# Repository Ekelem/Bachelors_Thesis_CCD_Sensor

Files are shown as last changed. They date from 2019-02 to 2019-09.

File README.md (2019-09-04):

# Bakalárska práca
Bakalárska práca VUT FIT, ROZŠIŘUJÍCÍ MODUL S CCD SENZOREM PRO VÝUKOVÝ KIT MINERVA

# Schémy

[Main](https://github.com/Ekelem/Bachelors_Thesis/blob/master/docs/ccdmodule.pdf)

[Image Sensor](https://github.com/Ekelem/Bachelors_Thesis/blob/master/docs/ImageSensor-Sheet5C7E7D75.pdf)

[Power Supply](https://github.com/Ekelem/Bachelors_Thesis/blob/master/docs/PowerSupply-Sheet5C7CB2BF.pdf)

# Preview

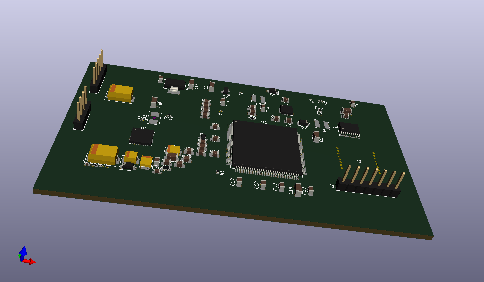
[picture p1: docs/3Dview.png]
alt Preview Preview


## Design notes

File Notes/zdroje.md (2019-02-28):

# Schémy
## Cam84 project
http://astroccd.org/wp-content/uploads/2015/05/CCD_Cam84_v41_sch.png
http://astroccd.org/2015/04/cam84/
https://stargazerslounge.com/topic/268504-a-diy-ccd-camera/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

## openmv boards (po digitalizácií môže byť použitý rovnaký image processing ako u CMOS kamier)
https://github.com/openmv/openmv-boards

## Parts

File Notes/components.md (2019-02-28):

#Súčiastky

## MCU
https://www.digikey.cz/product-detail/en/stmicroelectronics/STM32F765VGT6/497-16630-ND/6137841

## MPZ1608S181ATAH0
https://www.digikey.cz/product-detail/en/tdk-corporation/MPZ1608S181ATAH0/445-5220-1-ND/2117954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

## TPS65130 step up from 5 to 15 V and -8 V
https://www.mouser.sk/ProductDetail/Texas-Instruments/TPS65130RGER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

## Servo motor
https://www.gme.cz/servomotor-9g

## ICX098BQ
http://pdf1.alldatasheet.com/datasheet-pdf/view/88220/SONY/ICX098BQ.html
https://www.ebay.com/itm/1-x-ICXO98-ICX098-ICX098BQ-A-Progressive-Scan-CCD-Image-Sensor/183661486819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

119 Kč

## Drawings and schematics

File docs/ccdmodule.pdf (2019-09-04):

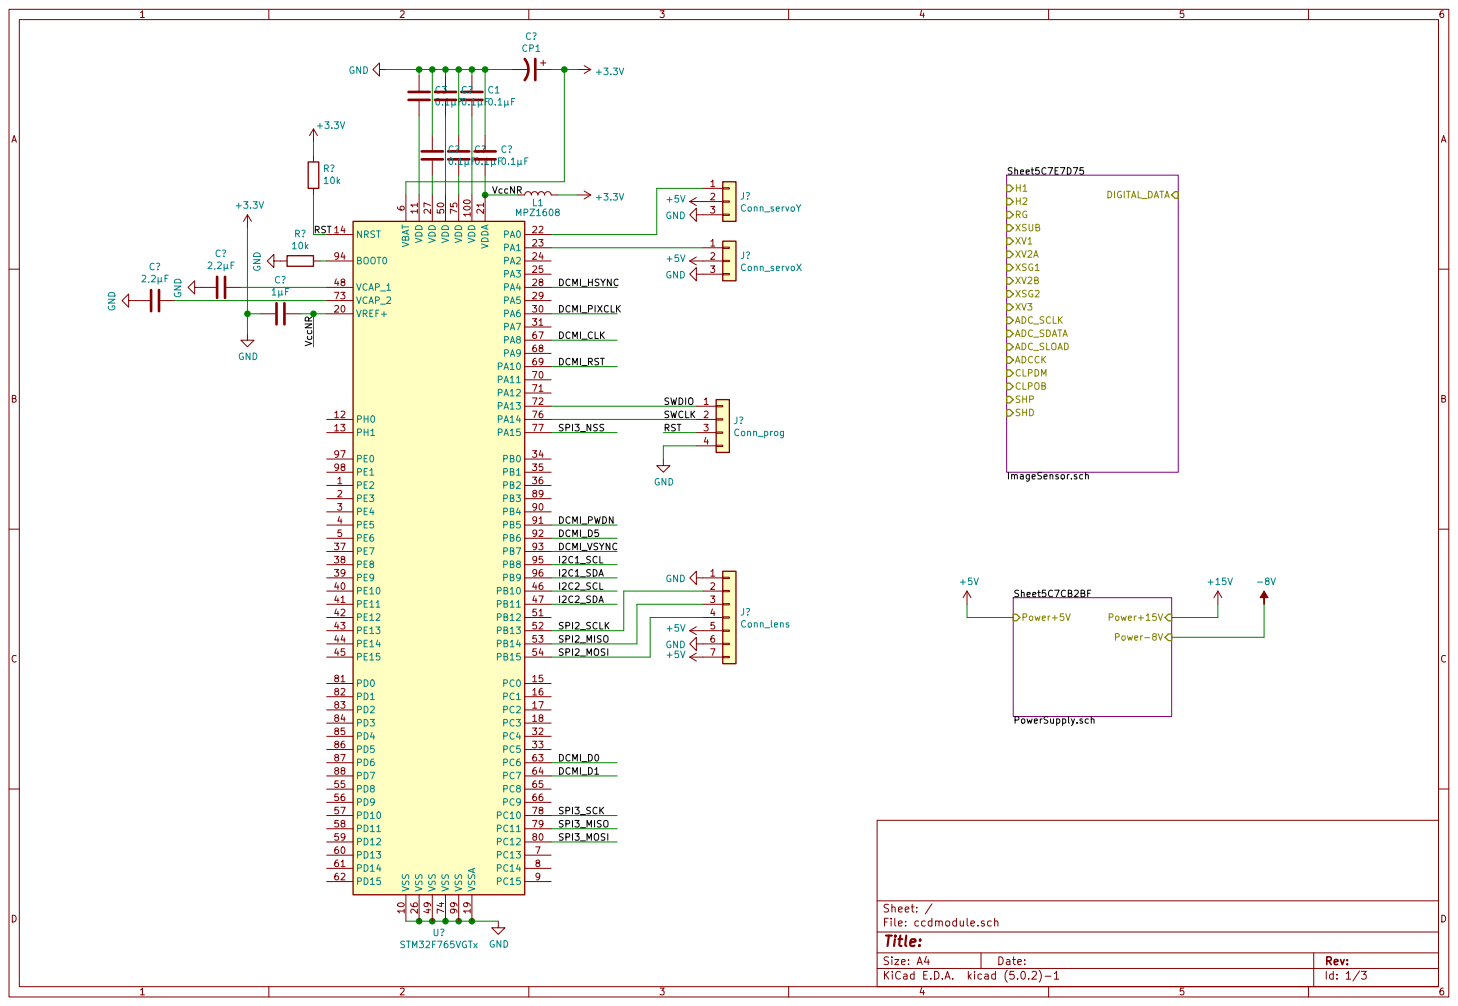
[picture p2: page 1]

Id: 1/3 Title: File: ccdmodule.sch Sheet: /

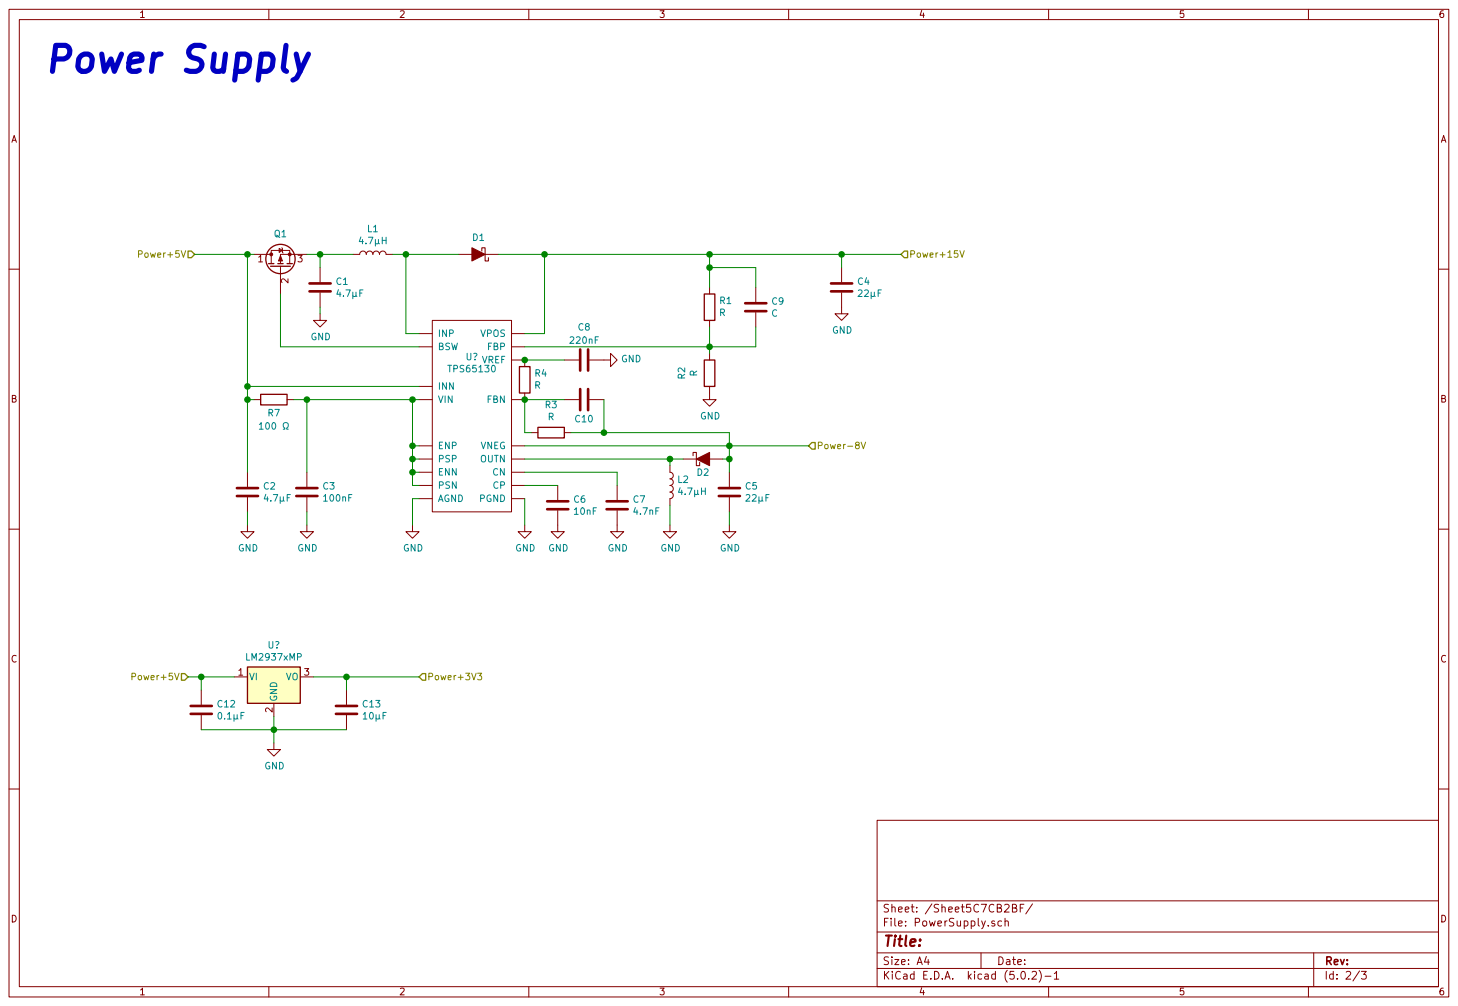
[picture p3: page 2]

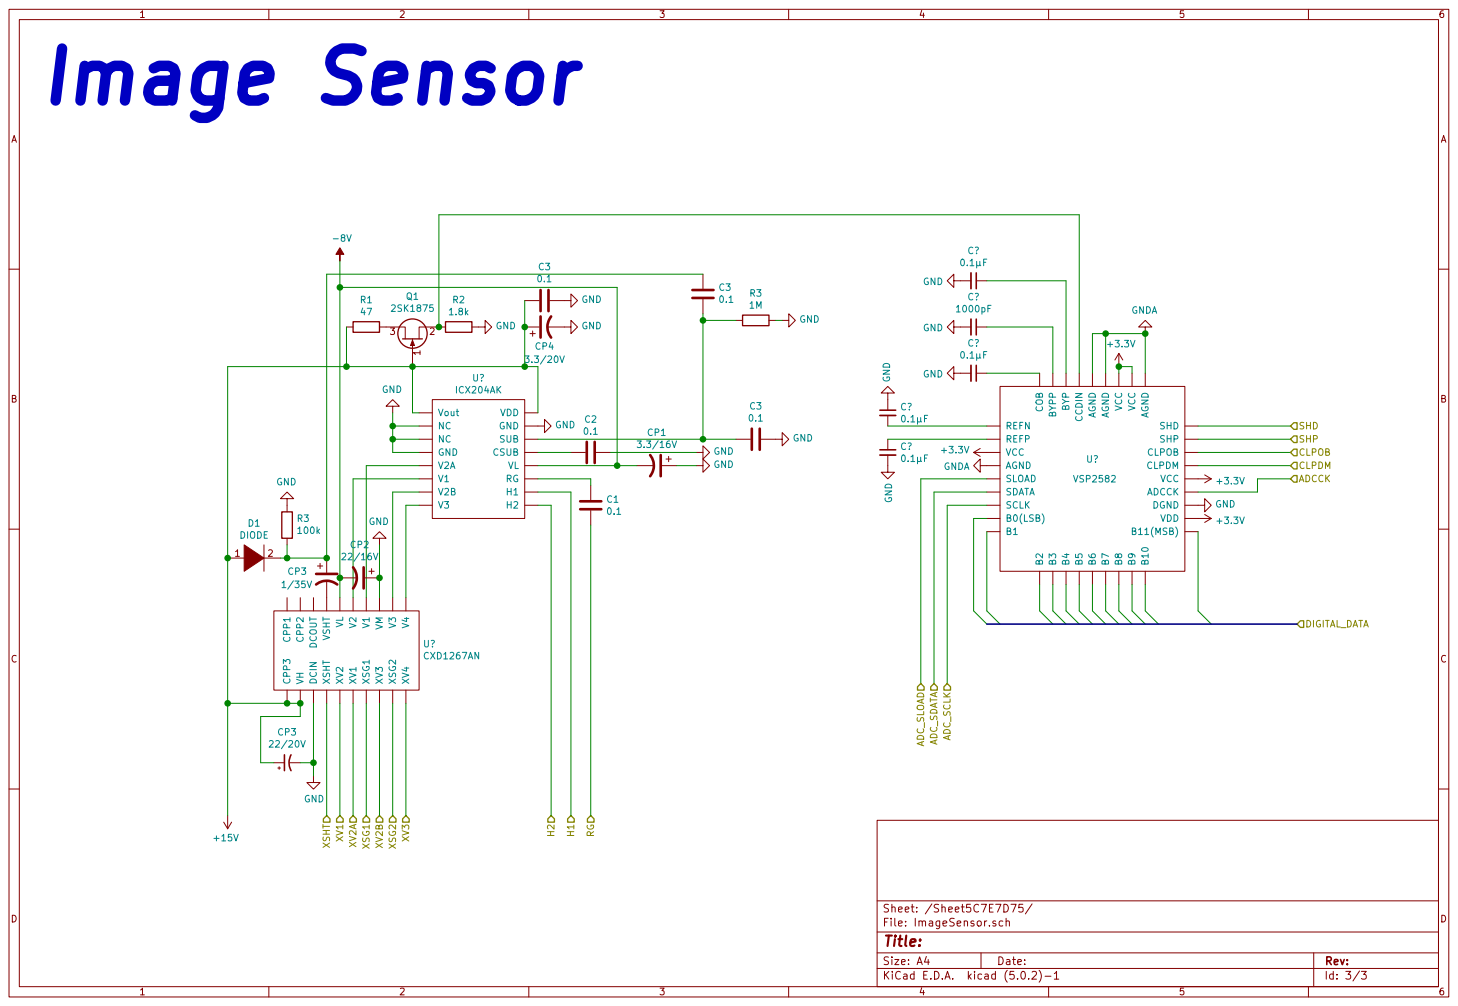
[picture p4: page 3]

File: ImageSensor.sch Sheet: /Sheet5C7E7D75/ Image Sensor

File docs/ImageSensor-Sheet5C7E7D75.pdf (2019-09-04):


File: ImageSensor.sch Sheet: /Sheet5C7E7D75/ Image Sensor


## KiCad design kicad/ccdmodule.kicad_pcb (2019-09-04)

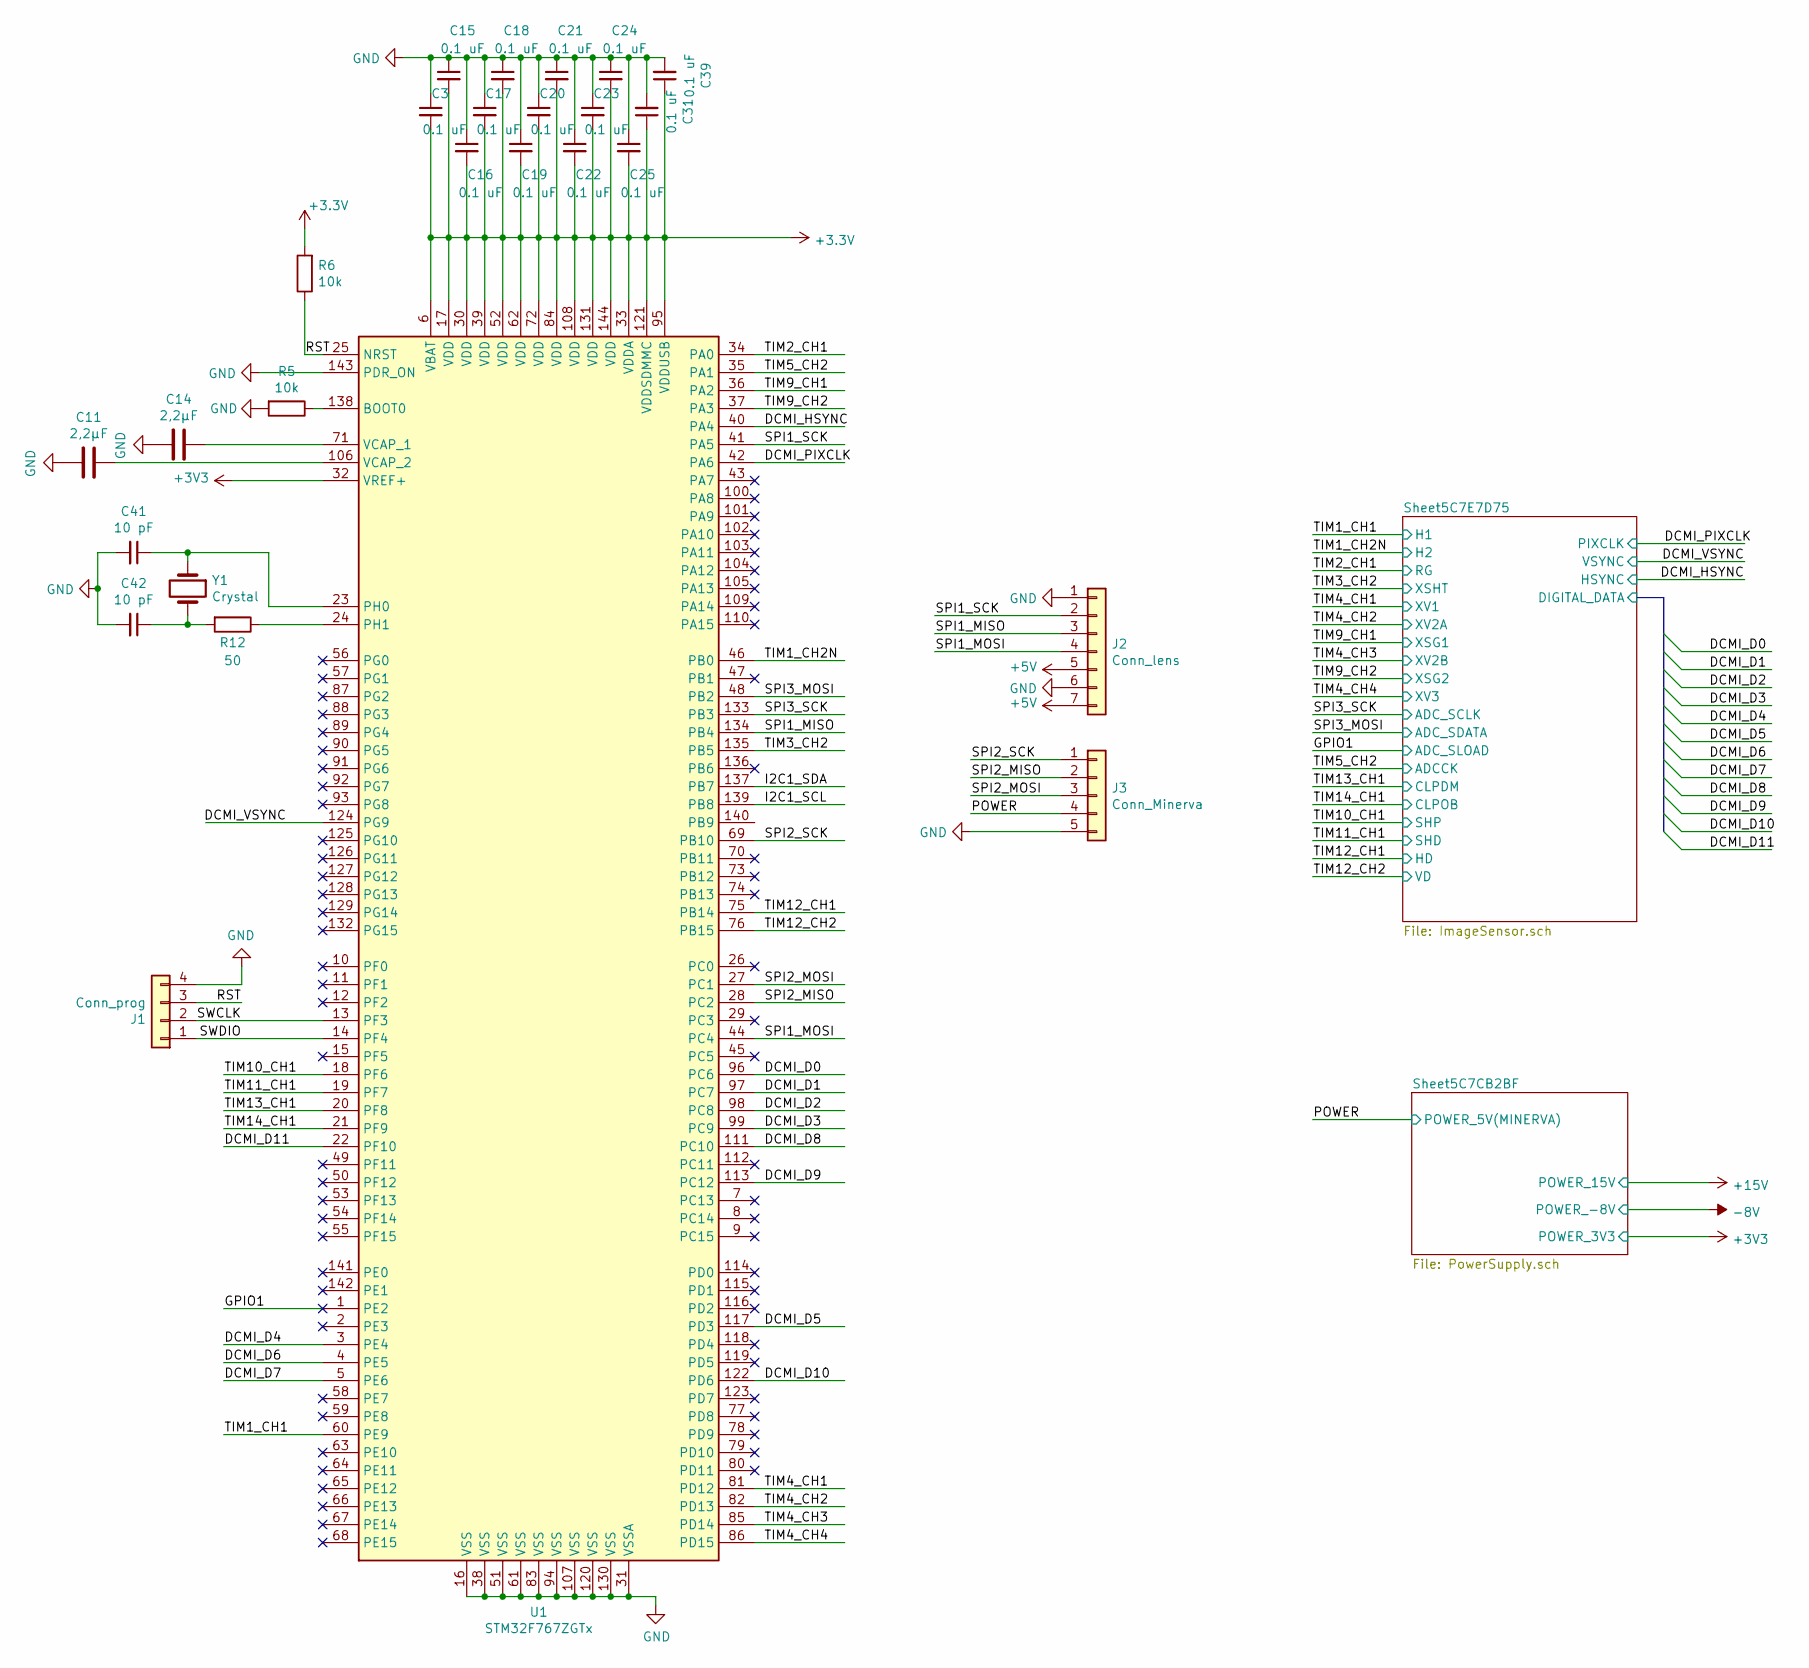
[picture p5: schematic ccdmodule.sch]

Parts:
C3, C15, C16, C17, C18, C19, C20, C21, C22, C23, C24, C25, C31, C39: 0.1 uF; C_0805_2012Metric
C11, C14: 2,2µF; C_1206_3216Metric
C41, C42: 10 pF; C_0201_0603Metric
J1: Conn_prog; PinHeader_1x04_P2.54mm_Vertical
J2: Conn_lens; PinHeader_1x07_P2.54mm_Vertical
J3: Conn_Minerva; PinHeader_1x05_P2.54mm_Vertical
R5, R6: 10k; R_0402_1005Metric
R12: 50; R_0402_1005Metric
U1: STM32F767ZGTx; LQFP-144_20x20mm_P0.5mm
Y1: Crystal; Crystal_SMD_5032-2Pin_5.0x3.2mm

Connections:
+3V3: C3.2, C15.2, C16.2, C17.2, C18.2, C19.2, C20.2, C21.2, C22.2, C23.2, C24.2, C25.2, C31.1, C39.1, R6.2, U1.6 (VBAT), U1.17 (VDD), U1.30 (VDD), U1.32 (VREF+), U1.33 (VDDA), U1.39 (VDD), U1.52 (VDD), U1.62 (VDD), U1.72 (VDD), U1.84 (VDD), U1.95 (VDDUSB), U1.108 (VDD), U1.121 (VDDSDMMC), U1.131 (VDD), U1.144 (VDD); also elsewhere on the board
+5V: J2.5, J2.7
/DCMI_D0: U1.96 (PC6)
/DCMI_D1: U1.97 (PC7)
/DCMI_D2: U1.98 (PC8)
/DCMI_D3: U1.99 (PC9)
/DCMI_D4: U1.3 (PE4)
/DCMI_D5: U1.117 (PD3)
/DCMI_D6: U1.4 (PE5)
/DCMI_D7: U1.5 (PE6)
/DCMI_D8: U1.111 (PC10)
/DCMI_D9: U1.113 (PC12)
/DCMI_D10: U1.122 (PD6)
/DCMI_D11: U1.22 (PF10)
/DCMI_HSYNC: U1.40 (PA4), U1.75 (PB14)
/DCMI_PIXCLK: U1.35 (PA1), U1.42 (PA6); also elsewhere on the board
/DCMI_VSYNC: U1.76 (PB15), U1.124 (PG9)
/GPIO1: U1.1 (PE2); also elsewhere on the board
/I2C1_SCL: U1.139 (PB8)
/I2C1_SDA: U1.137 (PB7)
/POWER: J3.4; also elsewhere on the board
/RST: J1.3, R6.1, U1.25 (NRST)
/SPI1_MISO: J2.3, U1.134 (PB4)
/SPI1_MOSI: J2.4, U1.44 (PC4)
/SPI1_SCK: J2.2, U1.41 (PA5)
/SPI2_MISO: J3.2, U1.28 (PC2)
/SPI2_MOSI: J3.3, U1.27 (PC1)
/SPI2_SCK: J3.1, U1.69 (PB10)
/SPI3_MOSI: U1.48 (PB2); also elsewhere on the board
/SPI3_SCK: U1.133 (PB3); also elsewhere on the board
/SWCLK: J1.2, U1.13 (PF3)
/SWDIO: J1.1, U1.14 (PF4)
/TIM1_CH1: U1.60 (PE9); also elsewhere on the board
/TIM1_CH2N: U1.46 (PB0); also elsewhere on the board
/TIM2_CH1: U1.34 (PA0); also elsewhere on the board
/TIM3_CH2: U1.135 (PB5); also elsewhere on the board
/TIM4_CH1: U1.81 (PD12); also elsewhere on the board
/TIM4_CH2: U1.82 (PD13); also elsewhere on the board
/TIM4_CH3: U1.85 (PD14); also elsewhere on the board
/TIM4_CH4: U1.86 (PD15); also elsewhere on the board
/TIM9_CH1: U1.36 (PA2); also elsewhere on the board
/TIM9_CH2: U1.37 (PA3); also elsewhere on the board
/TIM10_CH1: U1.18 (PF6); also elsewhere on the board
/TIM11_CH1: U1.19 (PF7); also elsewhere on the board
/TIM13_CH1: U1.20 (PF8); also elsewhere on the board
/TIM14_CH1: U1.21 (PF9); also elsewhere on the board
GND: C3.1, C11.1, C14.1, C15.1, C16.1, C17.1, C18.1, C19.1, C20.1, C21.1, C22.1, C23.1, C24.1, C25.1, C31.2, C39.2, C41.2, C42.2, J1.4, J2.1, J2.6, J3.5, R5.2, U1.16 (VSS), U1.31 (VSSA), U1.38 (VSS), U1.51 (VSS), U1.61 (VSS), U1.83 (VSS), U1.94 (VSS), U1.107 (VSS), U1.120 (VSS), U1.130 (VSS), U1.143 (PDR_ON); also elsewhere on the board
unnamed: C11.2, U1.106 (VCAP_2)
unnamed: C14.2, U1.71 (VCAP_1)
unnamed: C41.1, U1.23 (PH0), Y1.1
unnamed: C42.1, R12.2, Y1.2
unnamed: R5.1, U1.138 (BOOT0)
unnamed: R12.1, U1.24 (PH1)

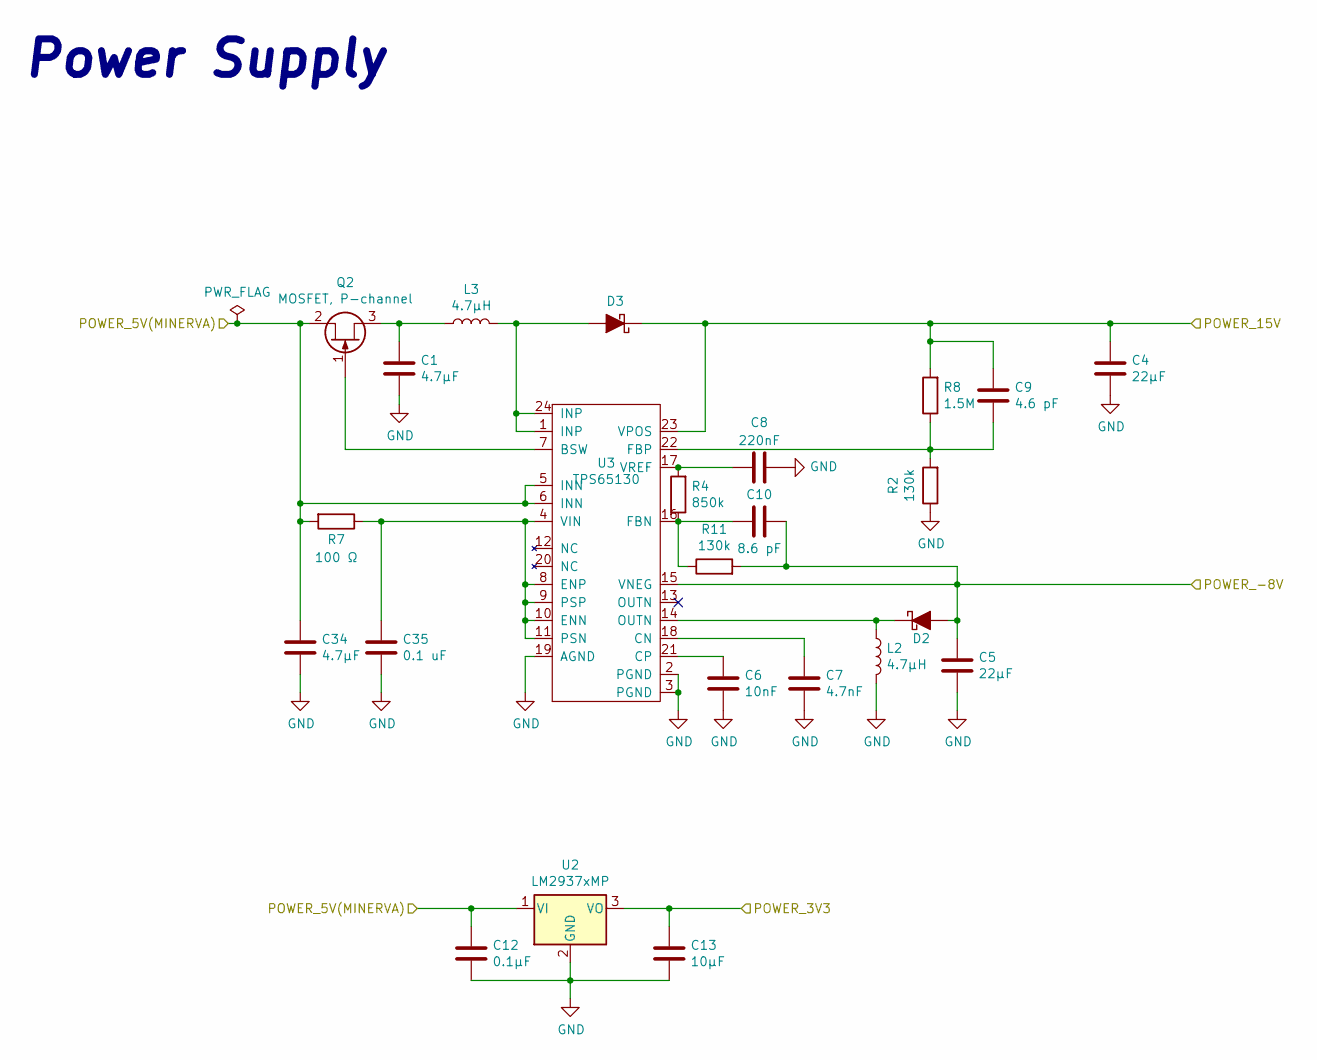
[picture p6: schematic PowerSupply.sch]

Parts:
C1: 4.7μF; C_1206_3216Metric
C4, C5: 22μF; C_0805_2012Metric
C6: 10nF; C_0805_2012Metric
C7: 4.7nF; C_0805_2012Metric
C8: 220nF; C_1206_3216Metric
C9: 4.6 pF; C_01005_0402Metric
C10: 8.6 pF; C_01005_0402Metric
C12: 0.1μF; C_1206_3216Metric
C13: 10μF; C_0805_2012Metric
C34: 4.7μF; C_0805_2012Metric
C35: 0.1 uF; C_0805_2012Metric
D2, D3: Schottky; D_SOD-123F
L2, L3: 4.7μH; L_Bourns-SRN4018
Q2: MOSFET, P-channel; SOT-23
R2, R11: 130k; R_0402_1005Metric
R4: 850k; R_0201_0603Metric
R7: 100 Ω; R_01005_0402Metric
R8: 1.5M; R_0201_0603Metric
U2: LM2937xMP; SOT-223-3_TabPin2
U3: TPS65130; QFN-24-1EP_4x4mm_P0.5mm_EP2.6x2.6mm

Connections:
+3V3: C13.1, U2.3 (VO); also elsewhere on the board
+15V: C4.1, C9.1, D3.1 (K), R8.2, U3.23 (VPOS); also elsewhere on the board
-8V: C5.1, C10.2, D2.2 (A), R11.2, U3.15 (VNEG); also elsewhere on the board
/POWER: C12.1, C34.1, Q2.2 (D), R7.2, U2.1 (VI), U3.5 (INN), U3.6 (INN); also elsewhere on the board
GND: C1.2, C4.2, C5.2, C6.2, C7.2, C8.1, C12.2, C13.2, C34.2, C35.2, L2.2, R2.1, U2.2 (GND), U3.2 (PGND), U3.3 (PGND), U3.19 (AGND); also elsewhere on the board
unnamed: C1.1, L3.1, Q2.3 (S)
unnamed: C6.1, U3.21 (CP)
unnamed: C7.1, U3.18 (CN)
unnamed: C8.2, R4.2, U3.17 (VREF)
unnamed: C9.2, R2.2, R8.1, U3.22 (FBP)
unnamed: C10.1, R4.1, R11.1, U3.16 (FBN)
unnamed: C35.1, R7.1, U3.4 (VIN), U3.8 (ENP), U3.9 (PSP), U3.10 (ENN), U3.11 (PSN)
unnamed: D2.1 (K), L2.1, U3.14 (OUTN)
unnamed: D3.2 (A), L3.2, U3.1 (INP), U3.24 (INP)
unnamed: Q2.1 (G), U3.7 (BSW)

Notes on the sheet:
Power Supply

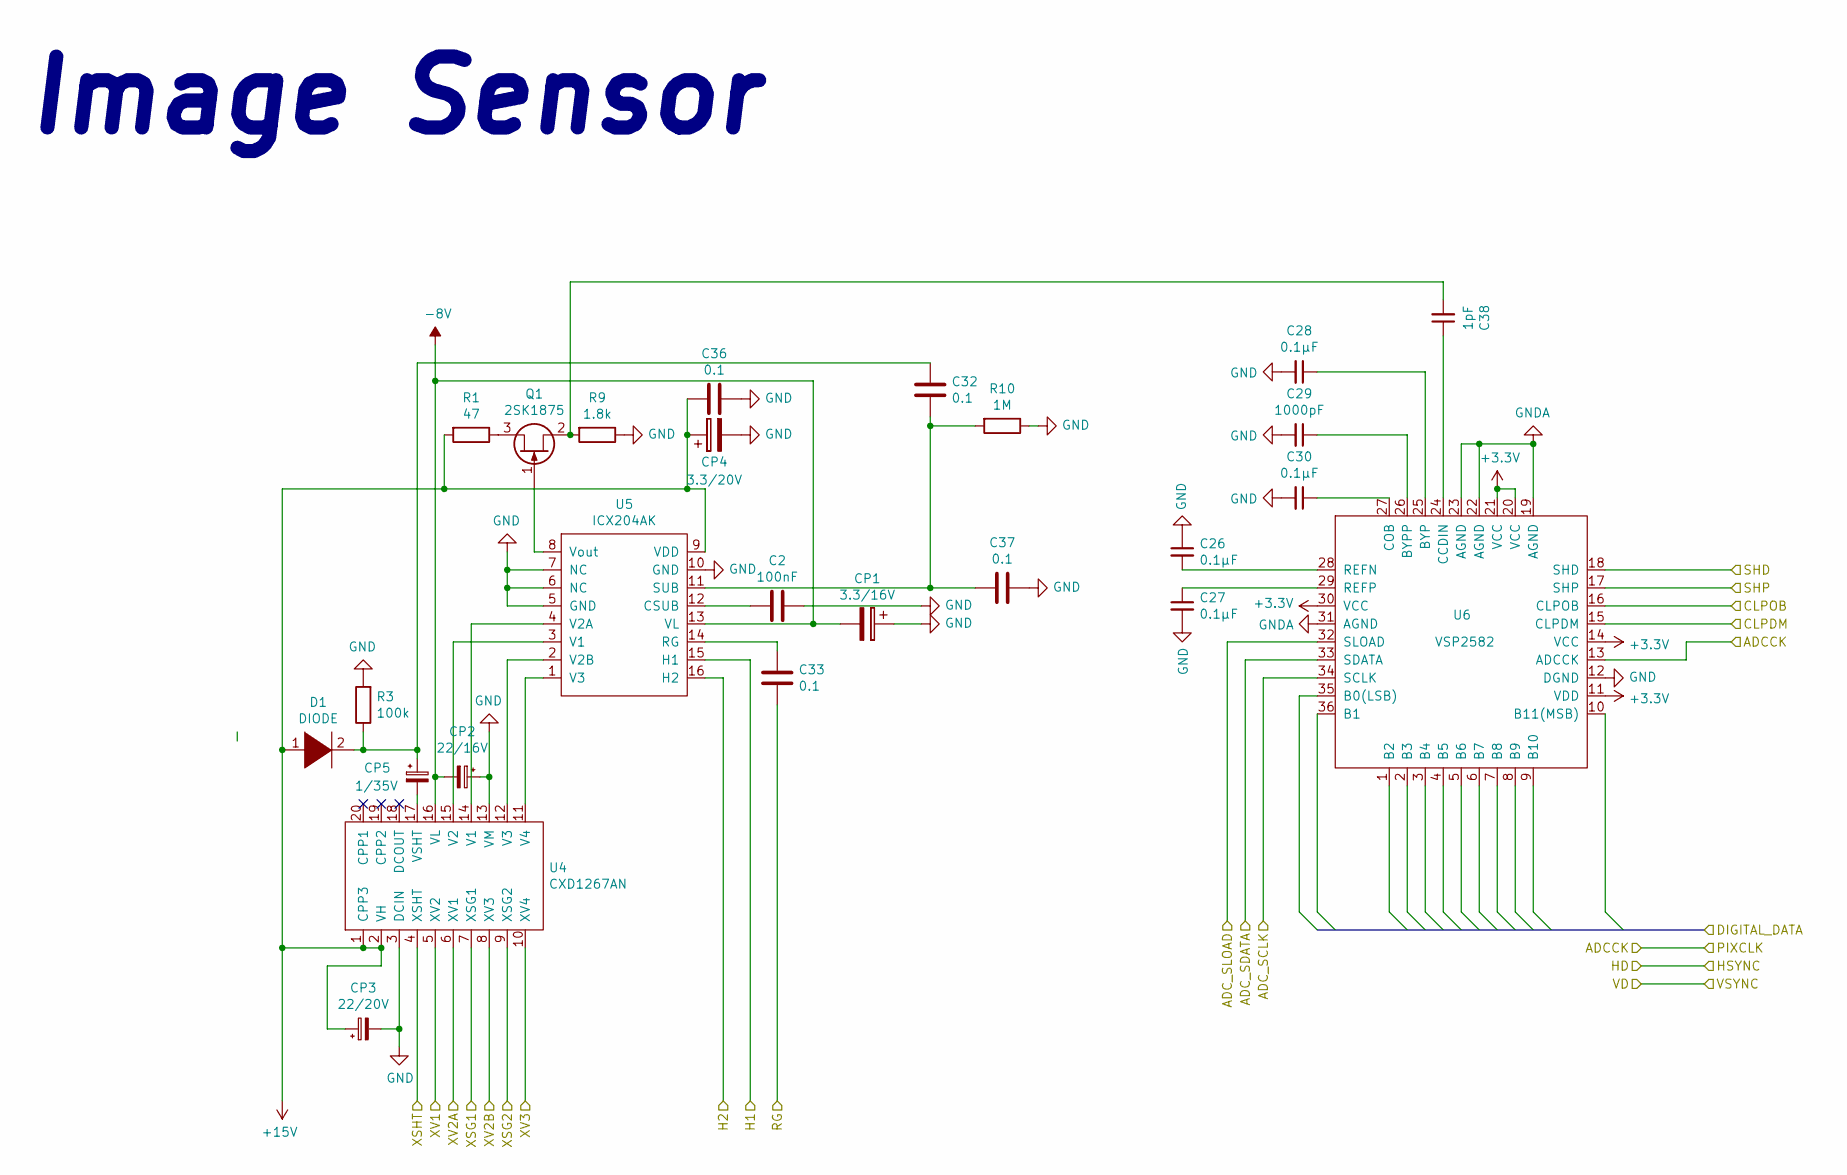
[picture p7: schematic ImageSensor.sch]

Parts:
C2: 100nF; C_1206_3216Metric
C26, C27, C28, C30: 0.1μF; C_0805_2012Metric
C29: 1000pF; C_0402_1005Metric
C32, C33, C36, C37: 0.1; C_0805_2012Metric
C38: 1pF; C_0603_1608Metric
CP1: 3.3/16V; CP_EIA-3528-12_Kemet-T
CP2: 22/16V; CP_EIA-7343-31_Kemet-D
CP3: 22/20V; CP_EIA-7343-31_Kemet-D
CP4: 3.3/20V; CP_EIA-3528-12_Kemet-T
CP5: 1/35V; CP_EIA-3528-21_Kemet-B
D1: DIODE; D_SOD-123
Q1: 2SK1875; SOT-323_SC-70
R1: 47; R_0201_0603Metric
R3: 100k; R_0805_2012Metric
R9: 1.8k; R_0201_0603Metric
R10: 1M; R_0402_1005Metric
U4: CXD1267AN; SSOP-20_4.4x6.5mm_P0.65mm
U5: ICX204AK; 16-DIP_sensor
U6: VSP2582; Texas_S-PVQFN-N36

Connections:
+3V3: U6.11 (VDD), U6.14 (VCC), U6.20 (VCC), U6.21 (VCC), U6.30 (VCC); also elsewhere on the board
+15V: C36.1, CP3.1, CP4.1, D1.1 (K), R1.2, U4.1 (CPP3), U4.2 (VH), U5.9 (VDD); also elsewhere on the board
-8V: CP1.2, CP2.2, U4.16 (VL), U5.13 (VL); also elsewhere on the board
/DCMI_PIXCLK: U6.13 (ADCCK); also elsewhere on the board
/GPIO1: U6.32 (SLOAD); also elsewhere on the board
/SPI3_MOSI: U6.33 (SDATA); also elsewhere on the board
/SPI3_SCK: U6.34 (SCLK); also elsewhere on the board
/TIM1_CH1: U5.15 (H1); also elsewhere on the board
/TIM1_CH2N: U5.16 (H2); also elsewhere on the board
/TIM2_CH1: C33.2; also elsewhere on the board
/TIM3_CH2: U4.4 (XSHT); also elsewhere on the board
/TIM4_CH1: U4.5 (XV2); also elsewhere on the board
/TIM4_CH2: U4.6 (XV1); also elsewhere on the board
/TIM4_CH3: U4.8 (XV3); also elsewhere on the board
/TIM4_CH4: U4.10 (XV4); also elsewhere on the board
/TIM9_CH1: U4.7 (XSG1); also elsewhere on the board
/TIM9_CH2: U4.9 (XSG2); also elsewhere on the board
/TIM10_CH1: U6.17 (SHP); also elsewhere on the board
/TIM11_CH1: U6.18 (SHD); also elsewhere on the board
/TIM13_CH1: U6.15 (CLPDM); also elsewhere on the board
/TIM14_CH1: U6.16 (CLPOB); also elsewhere on the board
GND: C2.1, C26.1, C27.2, C28.2, C29.2, C30.2, C36.2, C37.1, CP1.1, CP2.1, CP3.2, CP4.2, R3.2, R9.1, R10.1, U4.3 (DCIN), U4.13 (VM), U5.5 (GND), U5.6 (NC), U5.7 (NC), U5.10 (GND), U6.12 (DGND); also elsewhere on the board
GNDA: U6.19 (AGND), U6.22 (AGND), U6.23 (AGND), U6.31 (AGND)
unnamed: C2.2, U5.12 (CSUB)
unnamed: C26.2, U6.28 (REFN)
unnamed: C27.1, U6.29 (REFP)
unnamed: C28.1, U6.25 (BYP)
unnamed: C29.1, U6.26 (BYPP)
unnamed: C30.1, U6.27 (COB)
unnamed: C32.1, C37.2, R10.2, U5.11 (SUB)
unnamed: C32.2, CP5.1, D1.2 (A), R3.1
unnamed: C33.1, U5.14 (RG)
unnamed: C38.1, U6.24 (CCDIN)
unnamed: C38.2, Q1.2 (S), R9.2
unnamed: CP5.2, U4.17 (VSHT)
unnamed: Q1.1 (G), U5.8 (Vout)
unnamed: Q1.3 (D), R1.1
unnamed: U4.11 (V4), U5.1 (V3)
unnamed: U4.12 (V3), U5.2 (V2B)
unnamed: U4.14 (V1), U5.4 (V2A)
unnamed: U4.15 (V2), U5.3 (V1)

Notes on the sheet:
Image Sensor

Board: 2 copper layers, 76 parts (0 on the bottom side), 70 nets, no tracks yet.

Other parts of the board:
C40: 4.7 uF; C_1206_3216Metric

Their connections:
+3V3: C40.1; also elsewhere on the board
GND: C40.2; also elsewhere on the board

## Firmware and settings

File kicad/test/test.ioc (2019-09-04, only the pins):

Mcu.UserName=STM32F767ZGTx
PA0/WKUP.Signal=S_TIM5_CH1
PA1.Signal=S_TIM5_CH2
PA2.Signal=S_TIM9_CH1
PA3.Signal=S_TIM9_CH2
PA4.Signal=DCMI_HSYNC
PA5.Signal=S_TIM2_CH1_ETR
PA6.Signal=DCMI_PIXCLK
PA7.Signal=S_TIM3_CH2
PB0.Signal=TIM1_CH2N
PB10.Signal=SPI2_SCK
PB14.Signal=S_TIM12_CH1
PB15.Signal=S_TIM12_CH2
PB4.Signal=SPI1_MISO
PB6.Signal=I2C1_SCL
PB7.Signal=I2C1_SDA
PC1.Signal=SPI2_MOSI
PC10.Signal=DCMI_D8
PC12.Signal=DCMI_D9
PC2.Signal=SPI2_MISO
PC6.Signal=DCMI_D0
PC7.Signal=DCMI_D1
PC8.Signal=DCMI_D2
PC9.Signal=DCMI_D3
PD12.Signal=S_TIM4_CH1
PD13.Signal=S_TIM4_CH2
PD14.Signal=S_TIM4_CH3
PD15.Signal=S_TIM4_CH4
PD3.Signal=DCMI_D5
PD6.Signal=DCMI_D10
PD7.Signal=SPI1_MOSI
PE4.Signal=DCMI_D4
PE5.Signal=DCMI_D6
PE6.Signal=DCMI_D7
PE9.Signal=S_TIM1_CH1
PF10.Signal=DCMI_D11
PF6.Signal=S_TIM10_CH1
PF7.Signal=S_TIM11_CH1
PF8.Signal=S_TIM13_CH1
PF9.Signal=S_TIM14_CH1
PG11.Signal=SPI1_SCK
PG9.Signal=DCMI_VSYNC

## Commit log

2019-03-03 image sensor datasheets
2019-09-04 kicad project files
    [ImageSensor.sch, PowerSupply.sch, ccdmodule.kicad_pcb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]
